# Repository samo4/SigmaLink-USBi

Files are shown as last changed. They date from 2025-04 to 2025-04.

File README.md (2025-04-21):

# SigmaLink USBi

The SigmaLink USBi is an all-in-one real-time programming interface.

## Testing

- [x] draws less than 500mA
- [ ] why female connector?
- [ ] _too little bulk capacitance on VBUS_ (100u at least)
- [ ] missing pullup on SDA
- [ ] wrong footprint 74LVC2G66
- [ ] wrong footprint B5819W SL
- [ ] Y1 has DNP?
- [ ] _missing pull up on I2C SDA line_
- [x] works with SigmaStudio aftter adding capacitance and pullup on SDA

## Original info

MAIN COORDINATOR: [Max Chan](https://github.com/xcvista)

SigmaLink USBi Pod Image

The SigmaLink USBi is a low-budget real-time programming device for the freeDSP and other DSP boards from Analog Devices. It is a new PCB design based on a CY7C68013 chip.

It has the same features as the Analog Devices USB interface (EVAL-ADUSB2EBZ), such as changing parameters while already using the freeDSP or easy changes of the schematic in SigmaStudio. You also can write your program to the EEPROM.

Please refer to the documentation for more information:

[Google Doc](https://docs.google.com/document/d/13BDac6Mss2I0CBOsSrk4YG-c8GQUpgU41vkwsMnYBss/edit?usp=sharing)

## License

This work and all other materials under https://github.com/freeDSP are licensed under a [Creative Commons Attribution Share-Alike 4.0 license](LICENSE.md). This allows for both personal and commercial derivative works, as long as they credit freeDSP and release their designs under the same license.

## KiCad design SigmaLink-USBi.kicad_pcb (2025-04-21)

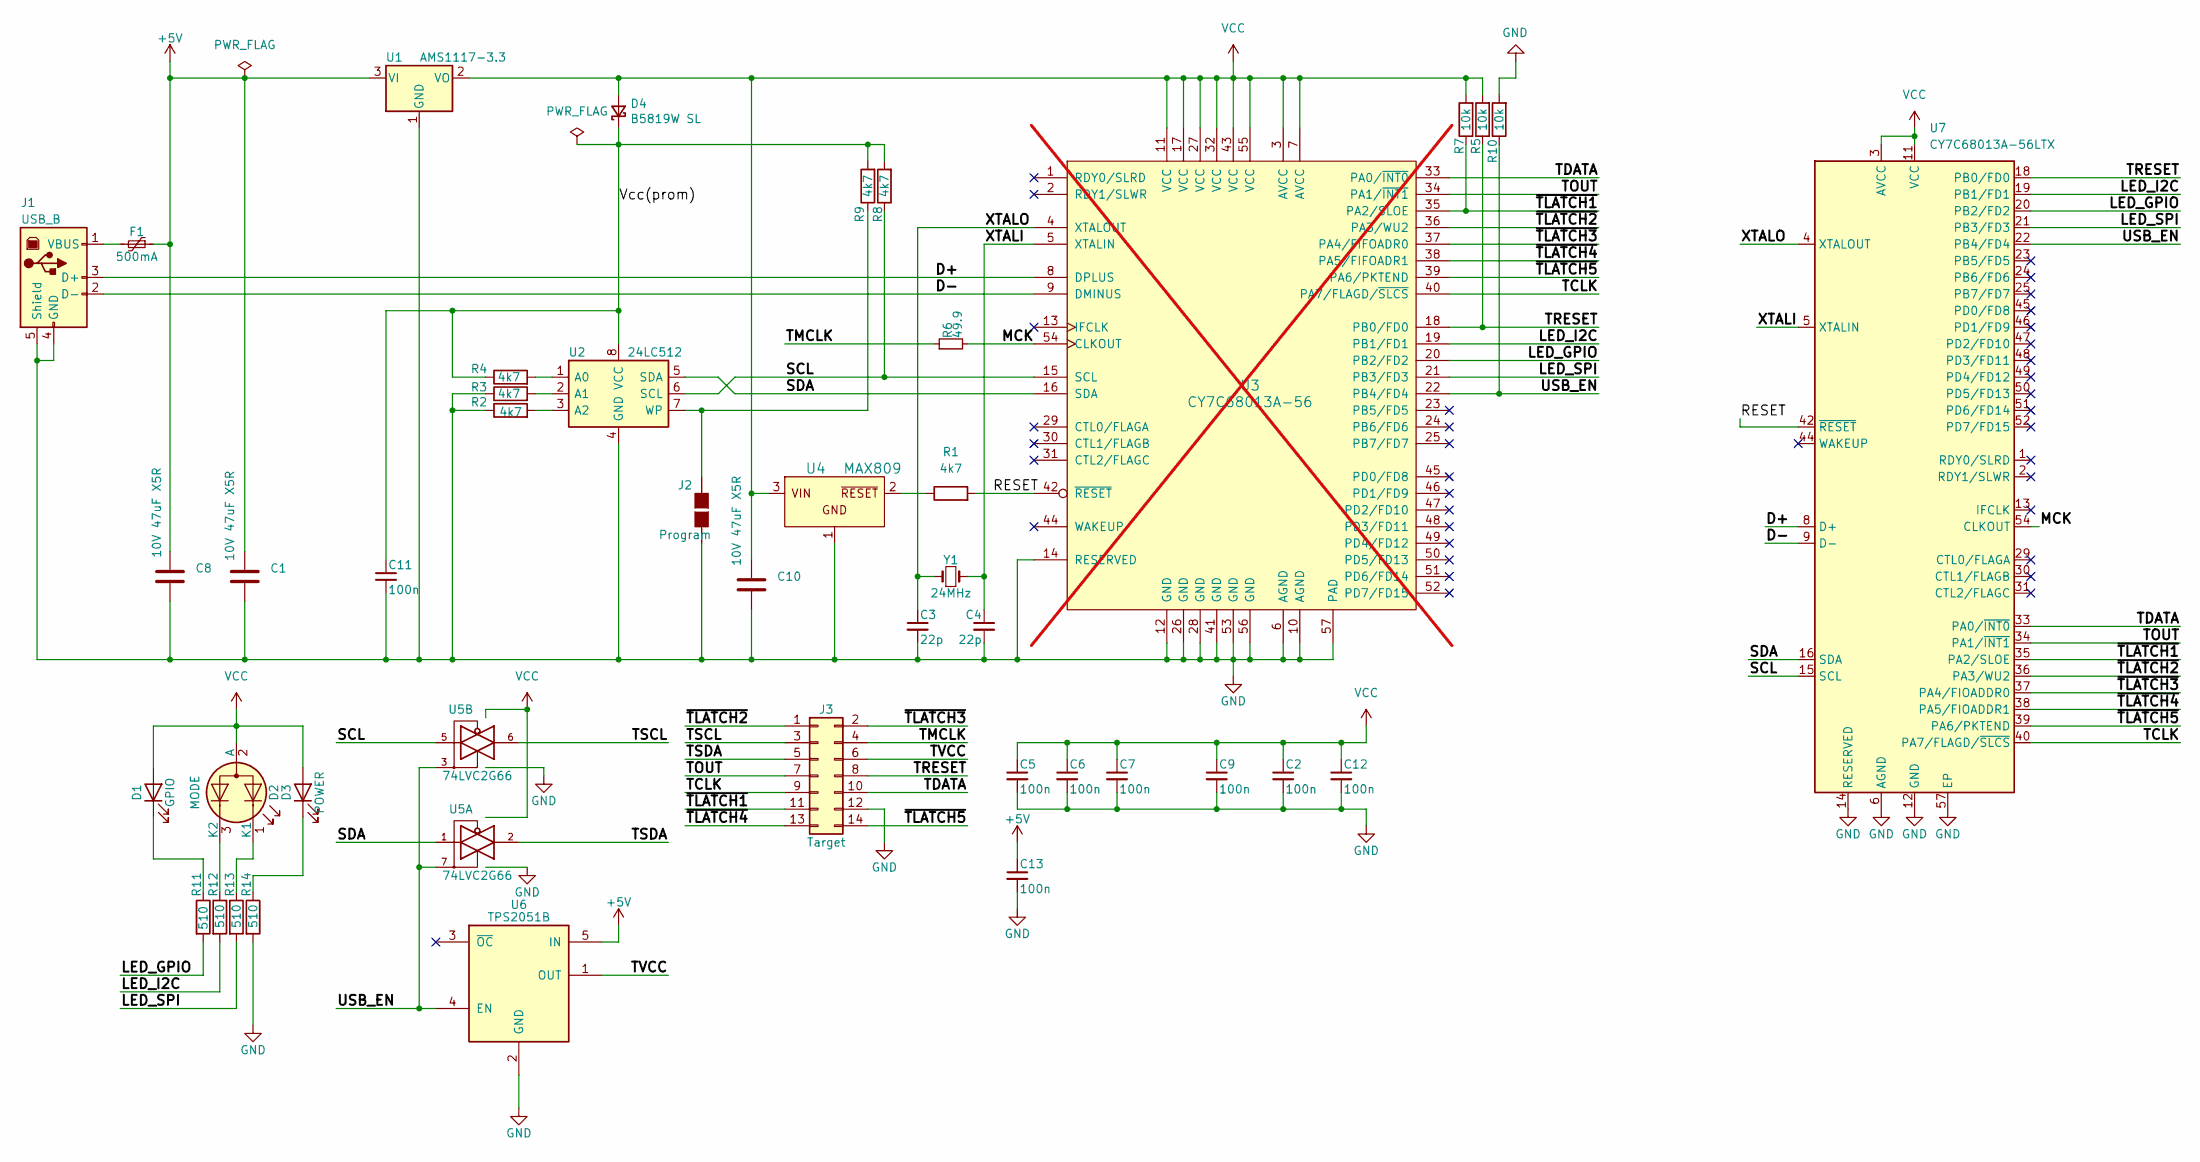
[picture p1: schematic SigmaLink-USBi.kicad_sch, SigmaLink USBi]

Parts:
C1, C8, C10: 10V 47uF X5R; C_1206_3216Metric; LCSC C96123
C2, C5, C6, C7, C9, C11, C12, C13: 100n; C_0402_1005Metric; LCSC C1525
C3, C4: 22p; C_0603_1608Metric; LCSC C1653
D1: GPIO; LED_D3.0mm; LCSC C86881
D2: MODE; LED_D3.0mm-3; LCSC C13559
D3: POWER; LED_D3.0mm; LCSC C85160
D4: B5819W SL; D_SOD-123; LCSC C8598
F1: 500mA; Fuse_1812_4532Metric_Pad1.30x3.40mm_HandSolder; LCSC C20979
J1: USB_B; USB_B_OST_USB-B1HSxx_Horizontal; LCSC C46392
J2: Program; PinHeader_1x02_P2.54mm_Vertical
J3: Target; IDC-Header_2x07_P2.54mm_Horizontal; LCSC C146622
R1, R2, R3, R4, R8, R9: 4k7; R_0402_1005Metric; LCSC C25900
R5, R7, R10: 10k; R_0402_1005Metric; LCSC C25744
R6: 49.9; R_0402_1005Metric
R11, R12, R13, R14: 510; R_0402_1005Metric; LCSC 0402
U1: AMS1117-3.3; SOT-223-3_TabPin2; LCSC C6186
U2: 24LC512; SOIC-8_3.9x4.9mm_P1.27mm; LCSC C6487
U3: CY7C68013A-56; QFN-56-1EP_8x8mm_P0.5mm_EP4.6x5.3mm; LCSC C14912; not fitted
U4: MAX809; SOT-23; LCSC C9965
U5: 74LVC2G66; VSSOP-8_3.0x3.0mm_P0.65mm; LCSC C181970
U6: TPS2051B; SOT-23-5; LCSC C24593
U7: CY7C68013A-56LTX; QFN-56-1EP_8x8mm_P0.5mm_EP4.5x5.2mm_ThermalVias_TopTented
Y1: 24MHz; Crystal_SMD_5032-2Pin_5.0x3.2mm; LCSC C122520

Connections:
+5V: C1.1, C8.1, C13.1, F1.1, U1.3 (VI), U6.5 (IN)
/D+: J1.3 (D+), U3.8 (DPLUS), U7.8 (D+)
/D-: J1.2 (D-), U3.9 (DMINUS), U7.9 (D-)
/LED_GPIO: R11.2, U3.20 (PB2/FD2), U7.20 (PB2/FD2)
/LED_I2C: R12.2, U3.19 (PB1/FD1), U7.19 (PB1/FD1)
/LED_SPI: R13.2, U3.21 (PB3/FD3), U7.21 (PB3/FD3)
/MCK: R6.2, U3.54 (CLKOUT), U7.54 (CLKOUT)
/RESET: R1.2, U3.42 (~RESET), U7.42 (~RESET)
/SCL: R8.1, U2.6 (SCL), U3.15 (SCL), U5.5, U7.15 (SCL)
/SDA: U2.5 (SDA), U3.16 (SDA), U5.1, U7.16 (SDA)
/TCLK: J3.9, U3.40 (PA7/FLAGD/~SLCS), U7.40 (PA7/FLAGD/~SLCS)
/TDATA: J3.10, U3.33 (PA0/~INT0), U7.33 (PA0/~INT0)
/TMCLK: J3.4, R6.1
/TOUT: J3.7, U3.34 (PA1/~INT1), U7.34 (PA1/~INT1)
/TRESET: J3.8, R5.1, U3.18 (PB0/FD0), U7.18 (PB0/FD0)
/TSCL: J3.3, U5.6
/TSDA: J3.5, U5.2
/TVCC: J3.6, U6.1 (OUT)
/USB_EN: R10.1, U3.22 (PB4/FD4), U5.3, U5.7, U6.4 (EN), U7.22 (PB4/FD4)
/Vcc(prom): C11.1, D4.1 (K), R4.1, R8.2, R9.2, U2.8 (VCC)
/XTALI: C4.1, U3.5 (XTALIN), U7.5 (XTALIN), Y1.2
/XTALO: C3.1, U3.4 (XTALOUT), U7.4 (XTALOUT), Y1.1
/~TLATCH1: J3.11, R7.1, U3.35 (PA2/SLOE), U7.35 (PA2/SLOE)
/~TLATCH2: J3.1, U3.36 (PA3/WU2), U7.36 (PA3/WU2)
/~TLATCH3: J3.2, U3.37 (PA4/FIFOADR0), U7.37 (PA4/FIOADDR0)
/~TLATCH4: J3.13, U3.38 (PA5/FIFOADR1), U7.38 (PA5/FIOADDR1)
/~TLATCH5: J3.14, U3.39 (PA6/PKTEND), U7.39 (PA6/PKTEND)
GND: C1.2, C2.2, C3.2, C4.2, C5.2, C6.2, C7.2, C8.2, C9.2, C10.2, C11.2, C12.2, C13.2, J1.4 (GND), J1.5 (Shield), J2.2 (G2), J3.12, R2.1, R3.1, R10.2, R14.2, U1.1 (GND), U2.4 (GND), U3.6 (AGND), U3.10 (AGND), U3.12 (GND), U3.14 (RESERVED), U3.26 (GND), U3.28 (GND), U3.41 (GND), U3.53 (GND), U3.56 (GND), U3.57 (PAD), U4.1 (GND), U5.4 (GND), U6.2 (GND), U7.6 (AGND), U7.10 (AGND), U7.12 (GND), U7.14 (RESERVED), U7.26 (GND), U7.28 (GND), U7.41 (GND), U7.53 (GND), U7.56 (GND), U7.57 (EP)
unnamed: D1.1 (K), R11.1
unnamed: D2.1 (K1), R13.1
unnamed: D2.3 (K2), R12.1
unnamed: D3.1 (K), R14.1
unnamed: F1.2, J1.1 (VBUS)
unnamed: J2.1 (G1), R9.1, U2.7 (WP)
unnamed: R4.2, U2.1 (A0)
unnamed: R3.2, U2.2 (A1)
unnamed: R2.2, U2.3 (A2)
unnamed: R1.1, U4.2 (~RESET)
VCC: C2.1, C5.1, C6.1, C7.1, C9.1, C10.1, C12.1, D1.2 (A), D2.2 (A), D3.2 (A), D4.2 (A), R5.2, R7.2, U1.2 (VO), U3.3 (AVCC), U3.7 (AVCC), U3.11 (VCC), U3.17 (VCC), U3.27 (VCC), U3.32 (VCC), U3.43 (VCC), U3.55 (VCC), U4.3 (VIN), U5.8 (VCC), U7.3 (AVCC), U7.7 (AVCC), U7.11 (VCC), U7.17 (VCC), U7.27 (VCC), U7.32 (VCC), U7.43 (VCC), U7.55 (VCC)

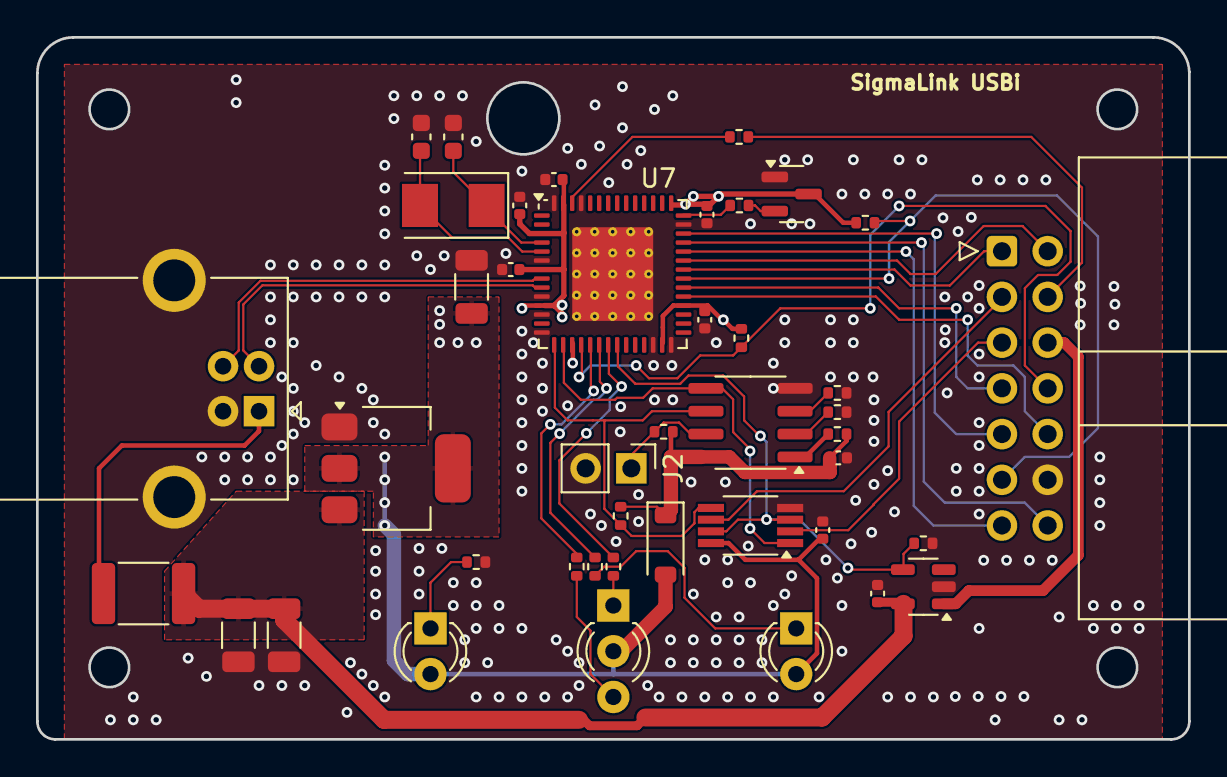
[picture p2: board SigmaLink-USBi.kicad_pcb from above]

Board: 2 copper layers, 64.0 x 39.0 mm, 42 parts (0 on the bottom side), 39 nets.
